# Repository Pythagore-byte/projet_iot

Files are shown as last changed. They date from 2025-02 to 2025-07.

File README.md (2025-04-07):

# projet_iot

## Project Overview

This repository contains an IoT project involving sensor data collection, backend processing, and a frontend dashboard. It encompasses Arduino firmware for sensor interfacing, a Python-based backend for data management and MQTT communication, a KiCad design for custom hardware, and a TypeScript/Next.js frontend for data visualization and user interaction.

## Key Features & Benefits

- **Multi-Sensor Integration:** Supports various sensors including temperature, humidity, soil moisture, CO2, and light.
- **LoRaWAN Connectivity:** Utilizes LoRaWAN for long-range, low-power data transmission.
- **Data Processing & Storage:** Employs a Python backend with SQLite database for data ingestion, processing, and storage.
- **Real-time Data Visualization:** Provides a user-friendly dashboard built with Next.js to monitor sensor data in real-time.
- **Custom Hardware Design:** Includes KiCad files for building custom PCB hardware.
- **Containerized Deployment:** Docker support for backend and frontend simplifies deployment and ensures consistency.

## Prerequisites & Dependencies

Before you begin, ensure you have the following installed:

- **Arduino IDE:** For flashing the Arduino firmware.
- **Python 3.11:** For running the backend server and related scripts.
- **Node.js and npm:** For building and running the frontend application.
- **Docker and Docker Compose:** For containerized deployment.
- **KiCad:** For viewing and editing the hardware design files.

**Specific Python Dependencies (Backend):**

- `fastapi`
- `uvicorn`
- `paho-mqtt`
- `sqlite3`
- `python-dotenv`

Install them using:

```bash
pip install -r backend/requirements.txt
```

**Specific Node.js Dependencies (Frontend):**

Refer to `frontend/package.json` for a complete list.  Install them using:

```bash
cd frontend
npm install
```

## Installation & Setup Instructions

Follow these steps to set up and run the project:

1. **Clone the Repository:**

   ```bash
   git clone https://github.com/Pythagore-byte/projet_iot.git
   cd projet_iot
   ```

2. **Arduino Firmware (Arduino_TTN):**

   - Open `Arduino_TTN/Arduino_TTN.ino` in the Arduino IDE.
   - Configure the necessary libraries and board settings for your specific hardware.
   - Modify the LoRaWAN credentials and sensor configurations as needed.
   - Upload the firmware to your Arduino device.

3. **Backend Setup:**

   - Navigate to the `backend` directory:

     ```bash
     cd backend
     ```

   -  Set up environment variables if needed (e.g., for production). Consider using `.env` file and `python-dotenv`.

   -  Initialize the database (if not already present):
      - Development Database:
        ```bash
        python dev_db_generator.py
        ```
      - Production Database:
        ```bash
        python prod_db_generator.py
        ```
      - Or use the provided `db.db` file.

   - Run the backend server:

     ```bash
     python server.py
     ```

     Alternatively, for Docker deployment, see step 5.

4. **Frontend Setup:**

   - Navigate to the `frontend` directory:

     ```bash
     cd ../frontend
     ```

   - Install the dependencies:

     ```bash
     npm install
     ```

   - Configure API endpoint in `frontend/lib/api.ts` to point to your backend server.

   - Run the development server:

     ```bash
     npm run dev
     ```

     This will start the frontend application, typically on `http://localhost:3000`.

5. **Docker Compose Deployment:**

   - From the project root directory, run:

     ```bash
     docker-compose up --build
     ```

   - This will build and start both the backend and frontend containers. Access the frontend through the port defined in the `docker-compose.yml` file (usually `http://localhost:3000`).

6. **KiCad Files (KICAD_FILES):**

   - Open the `.kicad_pcb` and `.kicad_sch` files in KiCad to view and modify the hardware design.

## Usage Examples & API Documentation

### Backend API (Example):

The backend provides a REST API for accessing sensor data.  Example endpoints:

- `GET /data`: Returns all sensor data.
- `GET /data/{device_id}`: Returns data for a specific device ID.

Refer to `backend/server.py` for detailed API route definitions.

### Frontend Usage:

The frontend provides a user interface for visualizing sensor data. Navigate to the appropriate page in your browser to see the collected data and related analysis. The routes `/soil-data`, `/temperature-humidity` and `/plant-suitability` will show the corresponding information.

## Configuration Options

### Backend Configuration:

- **Database Path:** The path to the SQLite database can be configured in `backend/server.py`.
- **MQTT Configuration:** The MQTT broker address, port, app ID, device ID and access key can be configured in `backend/mqtt_adder.py`.
- **Port:** The backend server port can be configured via the `--port` flag when starting the server (e.g., `uvicorn server:app --host 0.0.0.0 --port 8000`).

### Frontend Configuration:

- **API Endpoint:** The backend API endpoint URL should be defined in `frontend/lib/api.ts`.
- **Environment Variables:** Use environment variables in `next.config.js` to configure aspects of frontend deployment.

## Contributing Guidelines

We welcome contributions to this project! To contribute:

1. Fork the repository.
2. Create a new branch for your feature or bug fix.
3. Implement your changes.
4. Submit a pull request with a clear description of your changes.
5. Ensure code follows style conventions and has proper documentation.

## License Information

This project has no specific license specified. All rights are reserved by the owner.

## Acknowledgments

- This project utilizes open-source libraries and tools. We thank the developers and maintainers of these resources.

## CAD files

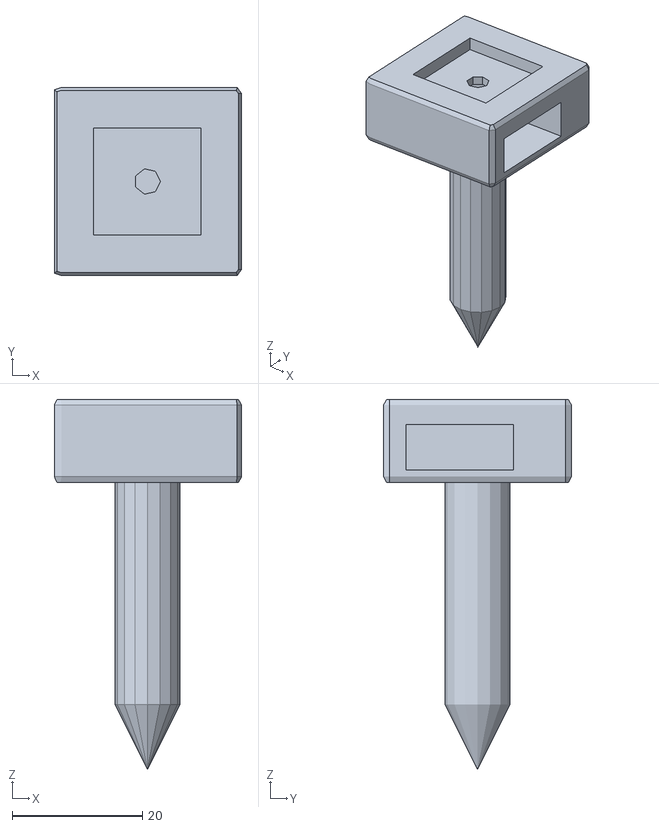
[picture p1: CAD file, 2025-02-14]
model/iteration1.stl
28.8 x 28.9 x 56.9

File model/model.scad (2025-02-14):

difference() {
    cylinder(h=35, r=5);
    translate([0,0,-2])cylinder(h=40, r=3);
}

difference() {
 translate([0,0,-10]) cylinder(h=10, r1=0 , r2=5);
 translate([0,0,-8]) cylinder(h=10, r1=0 , r2=5);
}

difference() {
    minkowski() {
        translate([0, 0, 40.5]) cube([27, 27, 11], center = true);
        sphere(r=1);                      
    }
    translate([0, 0, 46]) cube([16.5, 16.5, 3], center = true);
    translate([0, 0, 43]) cylinder(h=4, r=2, center = true);
    translate([-8.25, -11, 36]) cube([25, 16.5, 7], center = false);
    translate([-8.25, 8, 36]) cube([16.5, 8.5, 7], center = false);
    rotate([90, 0, 0]) translate([0, 39.5, -9]) cylinder(h=4, r=2); 
}
 

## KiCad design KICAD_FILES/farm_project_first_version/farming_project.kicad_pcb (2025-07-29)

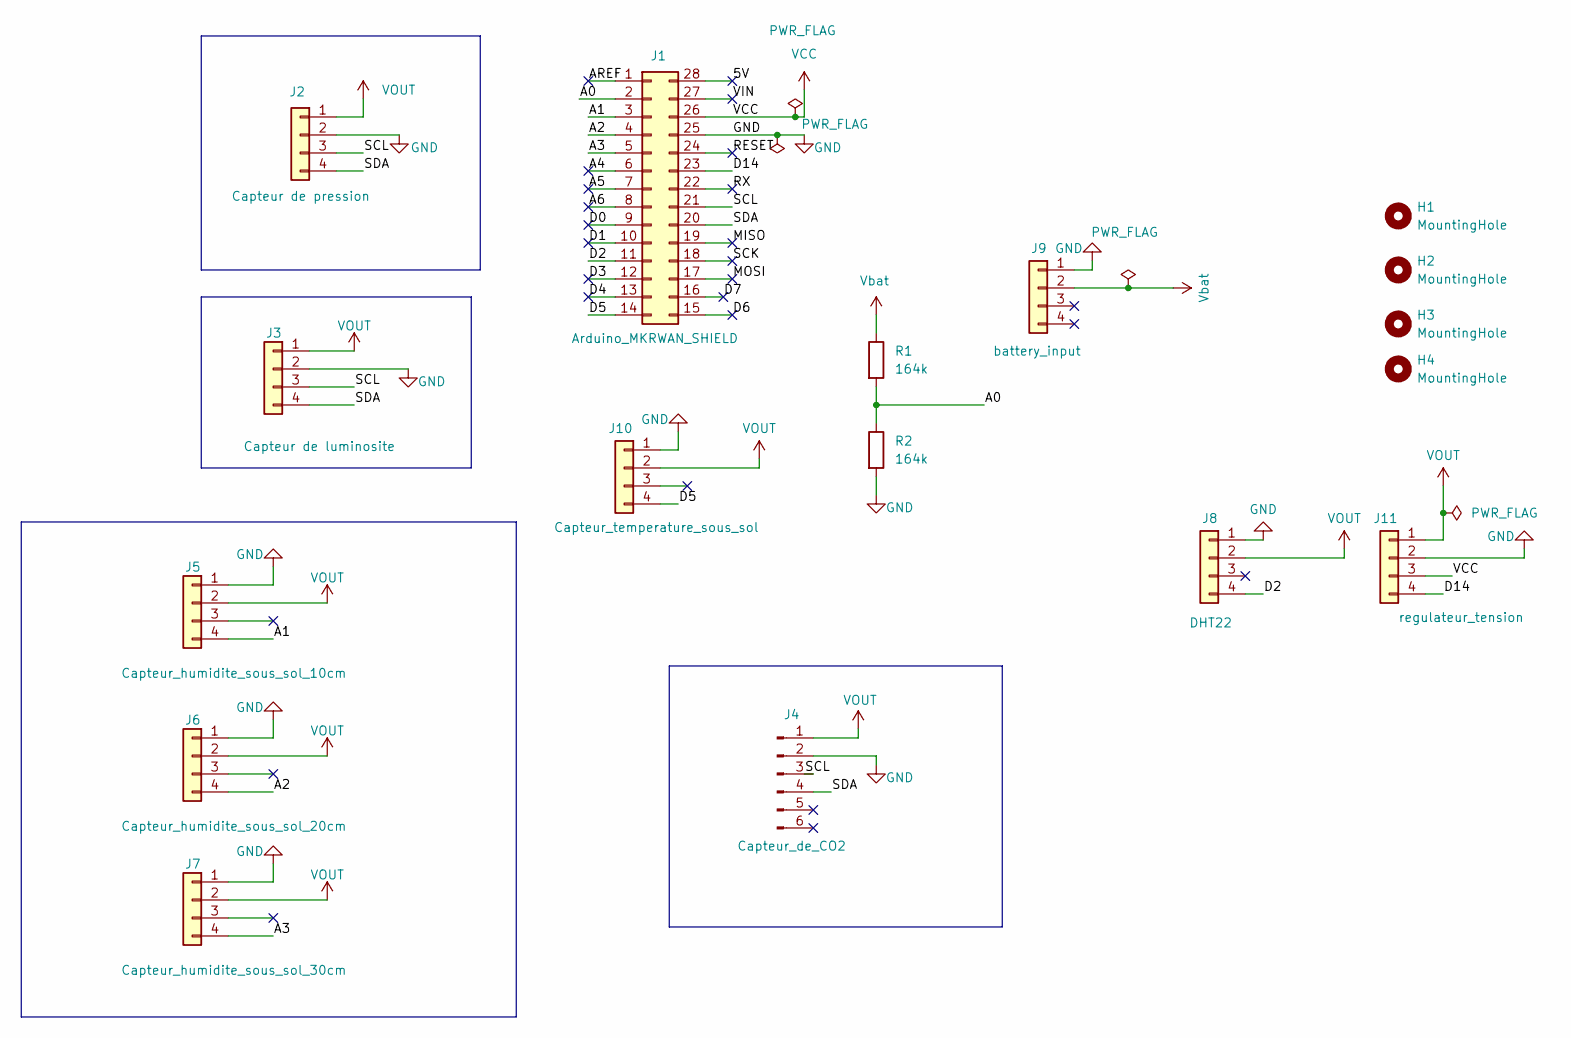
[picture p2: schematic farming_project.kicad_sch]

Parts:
H1, H2, H3, H4: MountingHole; MountingHole_2.5mm_Pad
J1: Arduino_MKRWAN_SHIELD; BOARD_ARDUINO_MKR_WAN_1310_MODIFIED
J2: Capteur de pression; PinSocket_1x04_P2.54mm_Vertical
J3: Capteur de luminosite; PinHeader_1x04_P2.54mm_Vertical
J4: Capteur_de_CO2; PinSocket_1x06_P2.54mm_Vertical
J5: Capteur_humidite_sous_sol_10cm; JST_PH_B4B-PH-K_1x04_P2.00mm_Vertical
J6: Capteur_humidite_sous_sol_20cm; JST_PH_B4B-PH-K_1x04_P2.00mm_Vertical
J7: Capteur_humidite_sous_sol_30cm; JST_PH_B4B-PH-K_1x04_P2.00mm_Vertical
J8: DHT22; JST_PH_B4B-PH-K_1x04_P2.00mm_Vertical
J9: battery_input; JST_PH_B4B-PH-K_1x04_P2.00mm_Vertical
J10: Capteur_temperature_sous_sol; JST_PH_B4B-PH-K_1x04_P2.00mm_Vertical
J11: regulateur_tension; PinHeader_1x04_P2.54mm_Vertical
R1, R2: 164k; R_Axial_DIN0309_L9.0mm_D3.2mm_P12.70mm_Horizontal

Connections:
/5V: J1.28
/A0: J1.2, R1.2, R2.1
/A1: J1.3, J5.4
/A2: J1.4, J6.4
/A3: J1.5, J7.4
/A4: J1.6
/A5: J1.7
/A6: J1.8
/AREF: J1.1
/D0: J1.9
/D1: J1.10
/D2: J1.11, J8.4
/D3: J1.12
/D4: J1.13
/D5: J1.14, J10.4
/D6: J1.15
/D7: J1.16
/D14: J1.23, J11.4
/MISO: J1.19
/MOSI: J1.17
/RESET: J1.24
/RX: J1.22
/SCK: J1.18
/SCL: J1.21, J2.3, J3.3, J4.3
/SDA: J1.20, J2.4, J3.4, J4.4
/VIN: J1.27
GND: J1.25, J2.2, J3.2, J4.2, J5.1, J6.1, J7.1, J8.1, J9.1, J10.1, J11.2, R2.2
VCC: J1.26, J11.3
VOUT: J2.1, J3.1, J4.1, J5.2, J6.2, J7.2, J8.2, J10.2, J11.1
Vbat: J9.2, R1.1

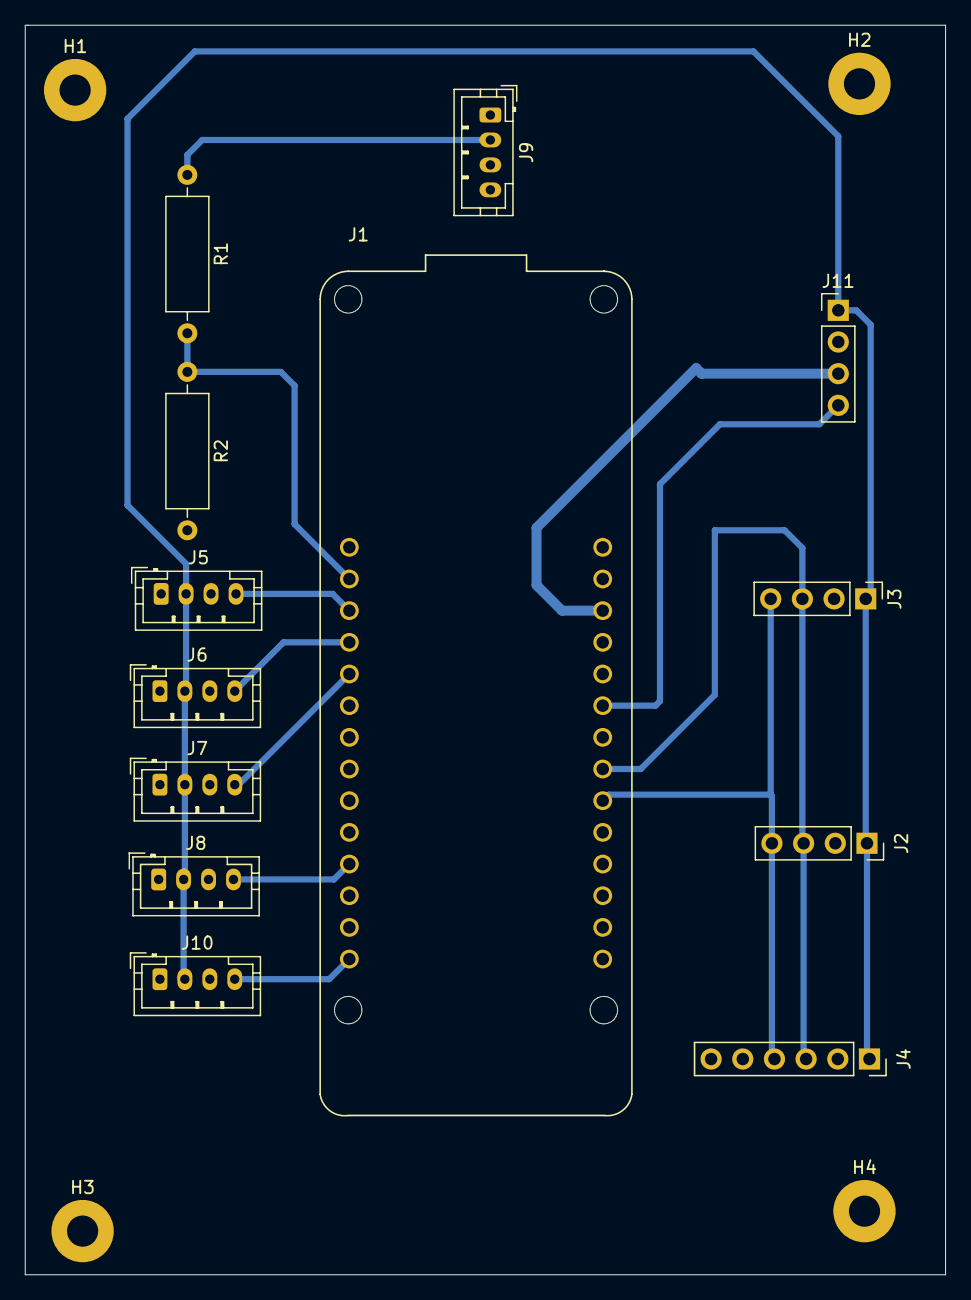
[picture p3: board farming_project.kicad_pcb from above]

Board: 2 copper layers, 73.8 x 100.2 mm, 17 parts (0 on the bottom side), 13 nets.

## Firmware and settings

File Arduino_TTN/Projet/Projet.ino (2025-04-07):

#include <ArduinoLowPower.h>
#include "BatterySensor.hpp"
#include "SoilMoistureSensor.hpp"
#include "LightSensor.hpp"
#include "CO2Sensor.hpp"
#include "SoilTemperatureSensor.hpp"
//#include "BMP388Sensor.hpp"
#include <DFRobot_BMP3XX.h>
#include "DHT22Sensor.hpp"  // Ajout du DHT22
#include "LoRaWan.hpp"

// Définition du bouton pour réveil
// const int buttonPin = 5;  // Modifier selon la broche utilisée
#define CALIBRATE_ABSOLUTE_DIFFERENCE

// Définition du capteur DHT22 (broche 4, à modifier si besoin)
DHT22Sensor dht22(2); // Prototype 7

// Création des objets capteurs
//BMP388Sensor bmp388;
DFRobot_BMP388_I2C sensor(&Wire, sensor.eSDOGND);
SoilTemperatureSensor soilTempSensor(5); // prototype 8
CO2Sensor co2Sensor;
LightSensor lightSensor(0x23);
SoilMoistureSensor sensor1(A1, 3800, 9); // 20cm
SoilMoistureSensor sensor2(A2, 3800, 14); //10cm
SoilMoistureSensor sensor3(A3, 3800, 6); // 30cm
BatterySensor battery(A0, 3.3, 2.0);


// Variable pour détecter un appui sur le bouton
volatile bool buttonPressed = false;

// Fonction d'interruption (réveil par bouton)
void wakeUp() {
    buttonPressed = true;
}

void setup() {
    Serial.begin(9600);

    pinMode(14, OUTPUT);  // Définit la broche en sortie D13 pour prototype
    digitalWrite(14, HIGH);  // Allume la sortie

    // Configuration LoRaWAN
    configureLoRaWAN();

    // Configuration du bouton avec interruption
    // pinMode(buttonPin, INPUT_PULLUP);
    // attachInterrupt(digitalPinToInterrupt(buttonPin), wakeUp, FALLING);

    int rslt;
    while( ERR_OK != (rslt = sensor.begin()) ){
      if(ERR_DATA_BUS == rslt){
        Serial.println("Data bus error!!!");
      }else if(ERR_IC_VERSION == rslt){
        Serial.println("Chip versions do not match!!!");
      }
      delay(3000);
    }
    Serial.println("Begin ok!");

    while( !sensor.setSamplingMode(sensor.eUltraPrecision) ){
        Serial.println("Set samping mode fail, retrying....");
        delay(3000);
      }
    
    delay(100);
    #ifdef CALIBRATE_ABSOLUTE_DIFFERENCE

    if( sensor.calibratedAbsoluteDifference(50.0) ){
        Serial.println("Absolute difference base value set successfully!");
      }
    #endif

    float sampingPeriodus = sensor.getSamplingPeriodUS();
    float sampingFrequencyHz = 1000000 / sampingPeriodus;      
    delay(1000);

    // Initialisation des capteurs
    soilTempSensor.init();
    battery.init();
    sensor1.init();
    sensor2.init();
    sensor3.init();
    lightSensor.init();
    co2Sensor.init();
    //bmp388.begin();
    dht22.begin();  // Initialisation du DHT22

    Serial.println("🌱 Système prêt !");
}

void loop() {


    // Pate régulateur 
    digitalWrite(14, HIGH);  // Allume la sortie
    delay(1000);

    // Packet LoRa
    uint8_t packet[20] = {0};
    
    Serial.println("🔵 Réveil du système, acquisition des données...");

    // Lecture des capteurs

      co2Sensor.restartSensor();  // Forcer un redémarrage complet du SCD30

    uint16_t co2 = co2Sensor.getCO2();
    if (co2 < 0) {
        Serial.println("❌ Capteur CO2 toujours inactif après redémarrage !");
    } else {
        Serial.print("💨 CO2: ");
        Serial.print(co2);
        Serial.println(" ppm");
    }

    // 🔄 Vérifier si les valeurs sont correctes après la mise en veille
    //uint16_t pression = bmp388.getPressure();
    //if (pression < 80000 || pression > 110000) {  // Pression anormale
    //    Serial.println("⚠️ Valeur anormale, reset du capteur...");
    //    bmp388.resetSensor();
    //    delay(1000);
    //    pression = bmp388.getPressure();
    //}
    float temperature = sensor.readTempC();
    float pression = sensor.readPressPa(); // Pression en Pa
    float altitude = sensor.readAltitudeM();
    Serial.print("Pression : ");
    Serial.print(pression); Serial.println(" Pa");
    Serial.print("Altitude : ");
    Serial.print(altitude); Serial.println(" m");
    Serial.print("Température : ");
    Serial.print(temperature); Serial.println(" °C");
    delay(1000);
    
    int16_t temp2 = soilTempSensor.getTemperature() *10; // sol
    int16_t temp1 = dht22.getTemperature() *10;   // air
    uint16_t  hum4 = dht22.getHumidity() *10; // air
    //uint16_t  co2 = co2Sensor.getCO2();   
    uint32_t  lum = lightSensor.getLux();
    uint16_t  hum3 = sensor1.getHumidityLevel() *10;  // sol 20cm
    int value = sensor1.getRawValue();
    Serial.println(value);
    uint16_t  hum2 = sensor2.getHumidityLevel() *10; // sol 10cm
    value = sensor1.getRawValue();
    Serial.println(value);
    uint16_t  hum1 = sensor3.getHumidityLevel() *10; // sol 30cm
    value = sensor1.getRawValue();
    Serial.println(value);
    uint8_t  batterie = battery.getBatteryPercentage();
    //uint16_t  pression = bmp388.getPressure();


  

    // Affichage des données
    Serial.println("----------------------");
    Serial.print("🔵 Pression: "); Serial.print(pression); Serial.println(" Pa");
    Serial.print("🌡 Température Air: "); Serial.print(temp1); Serial.println(" °C");
    Serial.print("🌡 Température Sol: "); Serial.print(temp2); Serial.println(" °C");
    Serial.print("💧 Humidité Air: "); Serial.print(hum4); Serial.println(" %");
    Serial.print("💨 CO2: "); Serial.print(co2); Serial.println(" ppm");
    Serial.print("☀️ LUX: "); Serial.print(lum); Serial.println(" lx");
    Serial.print("💧 Humidité Sol 10cm: "); Serial.print(hum3); Serial.println("%");
    Serial.print("💧 Humidité Sol 20cm: "); Serial.print(hum2); Serial.println("%");
    Serial.print("💧 Humidité Sol 30cm: "); Serial.print(hum1); Serial.println("%");
    Serial.print("🔋 Batterie: "); Serial.print(batterie); Serial.println("%"); 
    Serial.println("----------------------");

    //convertir pression qui est un float en uint16_t sachant que j'ai deja récupérer pression avant dans le code
    uint16_t pression1 = pression/10; // Conversion de float à uint16_t


    // Encodage des données
    packet[0] = temp1 & 0xFF;
    packet[1] = (temp1 >> 8) & 0xFF;
    packet[2] = temp2 & 0xFF;
    packet[3] = (temp2 >> 8) & 0xFF;
    packet[4] = hum1 & 0xFF;
    packet[5] = (hum1 >> 8) & 0xFF;
    packet[6] = hum2 & 0xFF;
    packet[7] = (hum2 >> 8) & 0xFF;
    packet[8] = hum3 & 0xFF;
    packet[9] = (hum3 >> 8) & 0xFF;
    packet[10] = hum4 & 0xFF;
    packet[11] = (hum4 >> 8) & 0xFF;
    packet[12] = lum & 0xFF;
    packet[13] = (lum >> 8) & 0xFF;
    packet[14] = (lum >> 16) & 0xFF;
    packet[15] = co2 & 0xFF;
    packet[16] = (co2 >> 8) & 0xFF;
    packet[17] = pression1 & 0xFF;
    packet[18] = (pression1 >> 8) & 0xFF;
    packet[19] = batterie & 0x7F;
    
        // Envoi des données
        bool ok = sendDataViaLoRa(packet, sizeof(packet));
    
        if (!ok) {
            Serial.println("⚠️ Tentative de reconnexion...");
            configureLoRaWAN();
        }

    // Attente pour affichage manuel
    //if (buttonPressed) {
    //    Serial.println("📟 Bouton pressé, maintien en éveil.");
    //    buttonPressed = false;
    //    delay(20000);  // Maintien actif 20 secondes après appui sur bouton
    //}

    Serial.println("😴 Mode sommeil...");
    digitalWrite(14, LOW);   // Éteint la sortie
    //delay(20000);
    //LowPower.deepSleep(10000);
    LowPower.deepSleep(600000);  // Mode sommeil pendant 10 minutes
}

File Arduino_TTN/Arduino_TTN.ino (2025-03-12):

#include <MKRWAN.h>

LoRaModem modem;  // Modem LoRa intégré au MKR WAN

// --- Paramètres TTN ---
// (À adapter avec tes vraies clés)
String devEUI = "70B3D57ED006E461";
String appEUI = "A8610A3435305F10";
String appKey = "BFF35E8B21DC13050FBBED93FCCD6BDA";

// --- Configuration de la région LoRa (EU868 pour l'Europe) ---
_lora_band region = EU868;

// -------------------------------------------------------------------------
// Configure le modem LoRa et tente la connexion OTAA à TTN
// -------------------------------------------------------------------------
void configureLoRaWAN() {
  Serial.println("=== Initialisation du modem LoRa ===");

  // Initialisation du modem
  if (!modem.begin(region)) {
    Serial.println("Erreur: impossible d'initialiser le modem !");
    while (1) {
      // Bloque le programme ici si échec.
      // (en production, on pourrait faire un reset ou un retry)
    }
  }

  Serial.println("=== Connexion OTAA en cours... ===");
  // OTAA join
  if (!modem.joinOTAA(appEUI, appKey, devEUI)) {
    Serial.println("Erreur: OTAA échouée !");
    while (1) {
      // Bloque si échec de join
    }
  }

  Serial.println("=== Connecté à TTN via OTAA ! ===");
}

// -------------------------------------------------------------------------
// Envoie un tableau de données sur le réseau LoRaWAN
// (renvoie vrai si succès, faux sinon)
// -------------------------------------------------------------------------
bool sendDataViaLoRa(uint8_t *data, size_t len) {
  // Prépare l'envoi
  modem.beginPacket();
  modem.write(data, len);

  // On utilise true pour un message confirmé
  int success = modem.endPacket(true);

  if (success > 0) {
    Serial.println("✅ Données LoRa envoyées avec succès !");
    return true;
  } else {
    Serial.println("❌ Échec de l'envoi LoRa !");
    return false;
  }
}

// -------------------------------------------------------------------------
// Setup : appelé une seule fois
// -------------------------------------------------------------------------
void setup() {
  Serial.begin(115200);
  while (!Serial) {
    ; // Attendre l'initialisation de la liaison Série
  }

  // Initialisation et connexion LoRaWAN
  configureLoRaWAN();
}

// -------------------------------------------------------------------------
// Loop : appelé en boucle
// -------------------------------------------------------------------------
void loop() {
  // --- Simulation des valeurs de capteurs ---
  int16_t temp1      = 215;    // 21,5°C -> stocké en "dixièmes de °C"
  int16_t temp2      = -30;    // -3,0°C
  uint16_t hum1      = 512;    // 51,2 %
  uint16_t hum2      = 487;    // 48,7 %
  uint16_t hum3      = 523;    // 52,3 %
  uint16_t hum4      = 450;    // 45,0 %
  uint32_t lum       = 35000;  // 35 000 lux
  uint16_t co2       = 4562;   // ppm
  uint16_t pression  = 1013;   // hPa
  uint8_t batterie   = 98;     // %

  // --- Création du tableau binaire (20 octets) ---
  uint8_t packet[20] = {0};

  // --- Encodage simple (2 octets pour chaque int16, etc.) ---
  // 1) temp1
  packet[0] = temp1 & 0xFF;
  packet[1] = (temp1 >> 8) & 0xFF;

  // 2) temp2
  packet[2] = temp2 & 0xFF;
  packet[3] = (temp2 >> 8) & 0xFF;

  // 3) hum1
  packet[4] = hum1 & 0xFF;
  packet[5] = (hum1 >> 8) & 0xFF;

  // 4) hum2
  packet[6] = hum2 & 0xFF;
  packet[7] = (hum2 >> 8) & 0xFF;

  // 5) hum3
  packet[8] = hum3 & 0xFF;
  packet[9] = (hum3 >> 8) & 0xFF;

  // 6) hum4
  packet[10] = hum4 & 0xFF;
  packet[11] = (hum4 >> 8) & 0xFF;

  // 7) lum (3 octets potentiels, mais on va en utiliser 3 max)
  packet[12] =  lum        & 0xFF;
  packet[13] = (lum >> 8)  & 0xFF;
  packet[14] = (lum >> 16) & 0xFF;

  // 8) co2
  packet[15] = co2 & 0xFF;
  packet[16] = (co2 >> 8) & 0xFF;

  // 9) pression
  packet[17] = pression & 0xFF;
  packet[18] = (pression >> 8) & 0xFF;

  // 10) batterie (un seul octet, max 127 ici)
  packet[19] = batterie & 0x7F; 

  // --- Tentative d'envoi ---
  bool ok = sendDataViaLoRa(packet, sizeof(packet));

  // Si l'envoi a échoué, on suppose qu'on a perdu la connexion → on retente le join
  if (!ok) {
    Serial.println("⚠️ Tentative de reconnexion...");
    configureLoRaWAN();
  }

  // Attendre 60 s avant la prochaine mesure
  delay(60000);
}

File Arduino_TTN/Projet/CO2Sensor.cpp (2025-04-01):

#include "CO2Sensor.hpp"

CO2Sensor::CO2Sensor(uint8_t i2cAddress) {
    _address = i2cAddress;
}

void CO2Sensor::init() {
    Serial.println("🔄 Réinitialisation du bus I2C...");
    Wire.end();  // Arrêter le bus I2C
    delay(100);
    Wire.begin();  // Redémarrer le bus I2C
    delay(100);

    Serial.println("🔄 Initialisation du capteur CO2...");
    _sensor.begin(Wire, _address);
    _sensor.softReset();
    delay(2000);  // Laisse le temps au capteur de redémarrer

    int16_t error = _sensor.readFirmwareVersion(_major, _minor);
    if (error != NO_ERROR) {
        Serial.println("❌ Erreur de lecture de la version du firmware du SCD30");
    } else {
        Serial.print("✅ SCD30 Firmware Version: ");
        Serial.print(_major);
        Serial.print(".");
        Serial.println(_minor);
    }

    _sensor.startPeriodicMeasurement(0);
    _sensor.setMeasurementInterval(2);
    Serial.println("📊 SCD30 prêt, en attente des premières mesures...");
}

void CO2Sensor::restartSensor() {
    Serial.println("🔄 Redémarrage manuel du SCD30...");
    Wire.end();  // Arrêter complètement l'I2C
    delay(100);
    Wire.begin();  // Redémarrer l'I2C
    delay(100);
    _sensor.begin(Wire, _address);
    delay(2000);
}

float CO2Sensor::getCO2() {
    uint16_t isReady = 0;
    int16_t error = _sensor.getDataReady(isReady);

    if (isReady) {
        float co2 = 0.0, temperature = 0.0, humidity = 0.0;
        delay(1500);
        error = _sensor.blockingReadMeasurementData(co2, temperature, humidity);

        if (error != NO_ERROR) {
            Serial.println("❌ Erreur lors de la lecture des données du SCD30");
            return -1;  // Valeur d'erreur
        }

        return co2;
    } else {
        Serial.println("⏳ Pas encore de données prêtes, attente...");
        return -1;  // Valeur d'erreur
    }
}

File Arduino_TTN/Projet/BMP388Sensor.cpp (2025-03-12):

#include "BMP388Sensor.hpp"

BMP388Sensor::BMP388Sensor(uint16_t altitude) : sensor(&Wire, sensor.eSDOGND) {
    altitudeBase = altitude;
}

bool BMP388Sensor::begin() {
    int rslt;
    while ((rslt = sensor.begin()) != ERR_OK) {
        if (rslt == ERR_DATA_BUS) {
            Serial.println("Erreur de bus I2C !");
        } else if (rslt == ERR_IC_VERSION) {
            Serial.println("Version du capteur incorrecte !");
        }
        delay(3000);
    }

    Serial.println("Capteur BMP388 initialisé avec succès !");

    while (!sensor.setSamplingMode(sensor.eUltraPrecision)) {
        Serial.println("Échec de la configuration du mode ultra précision, réessai...");
        delay(3000);
    }

    delay(100);
    
    if (sensor.calibratedAbsoluteDifference(altitudeBase)) {
        Serial.println("Calibration de l'altitude réussie !");
    }

    return true;
}

float BMP388Sensor::getPressure() {
    return sensor.readPressPa();
}

float BMP388Sensor::getSamplingPeriod() {
    return sensor.getSamplingPeriodUS();
}

float BMP388Sensor::getSamplingFrequency() {
    return 1000000.0 / sensor.getSamplingPeriodUS();
}

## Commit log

2025-02-14 Frontend files upload
    [iteration1.stl, model.scad]
2025-02-26 Sauvegarde des modifications avant checkout
2025-02-26 Receiver.py pour la connexion MQTT
2025-02-26 Refactor database schema by removing Type table and updating Device table constraints; enhance data insertion methods and API queries for improved measurement retrieval.
2025-03-11 added co2, pressure, luminosity and battery levels
2025-03-13 first version of pcb
    [farming_project-B_Adhesive.gbr, farming_project-B_Cu.gbl, farming_project-B_Cu.gbr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]
2025-03-15 deuxieme version PCB
    [farming_project.kicad_pcb, farming_project.kicad_sch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]
2025-03-20 mise a jour des code
2025-04-01 Add sensor value validation and timezone conversion for error timestamps
2025-04-06 Enhance error handling and add graph maximization feature in temperature and humidity page
2025-07-29 mise a jour
    [farming_project.kicad_pcb, farming_project.kicad_sch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]
